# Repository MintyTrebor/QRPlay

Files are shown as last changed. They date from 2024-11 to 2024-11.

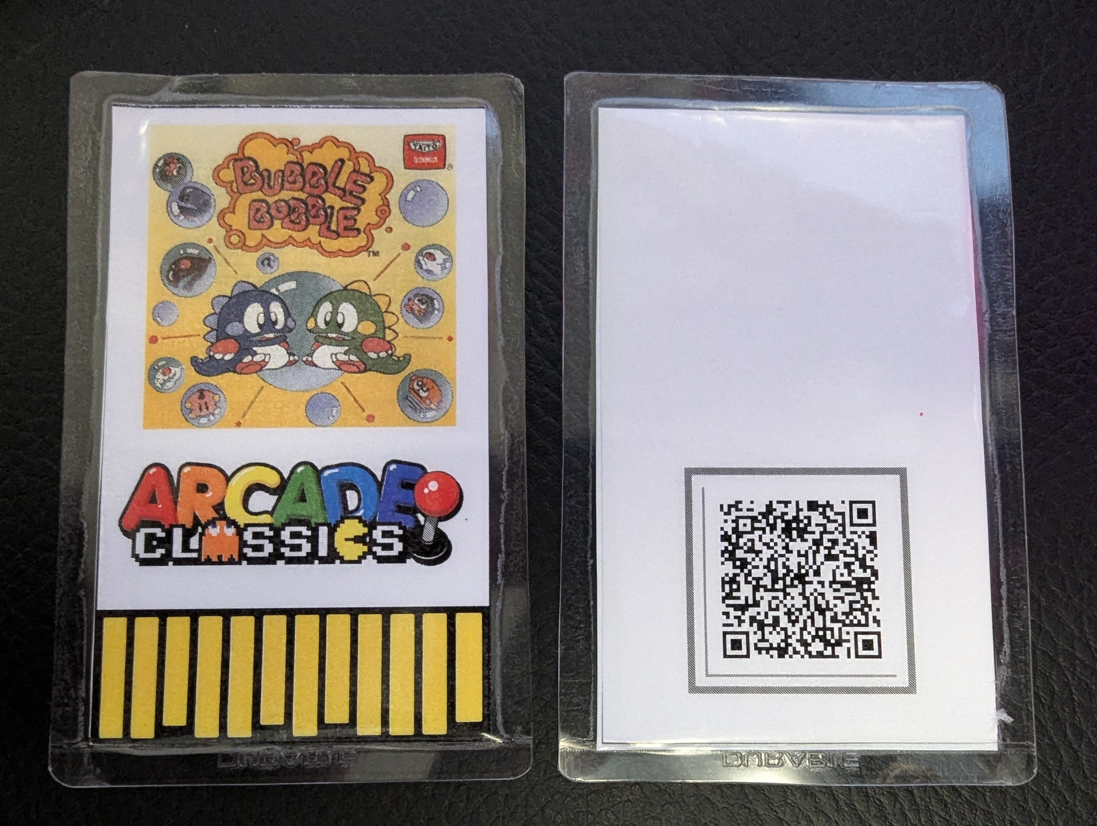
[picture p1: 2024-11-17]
media/PXL_20241114_154618407.jpg

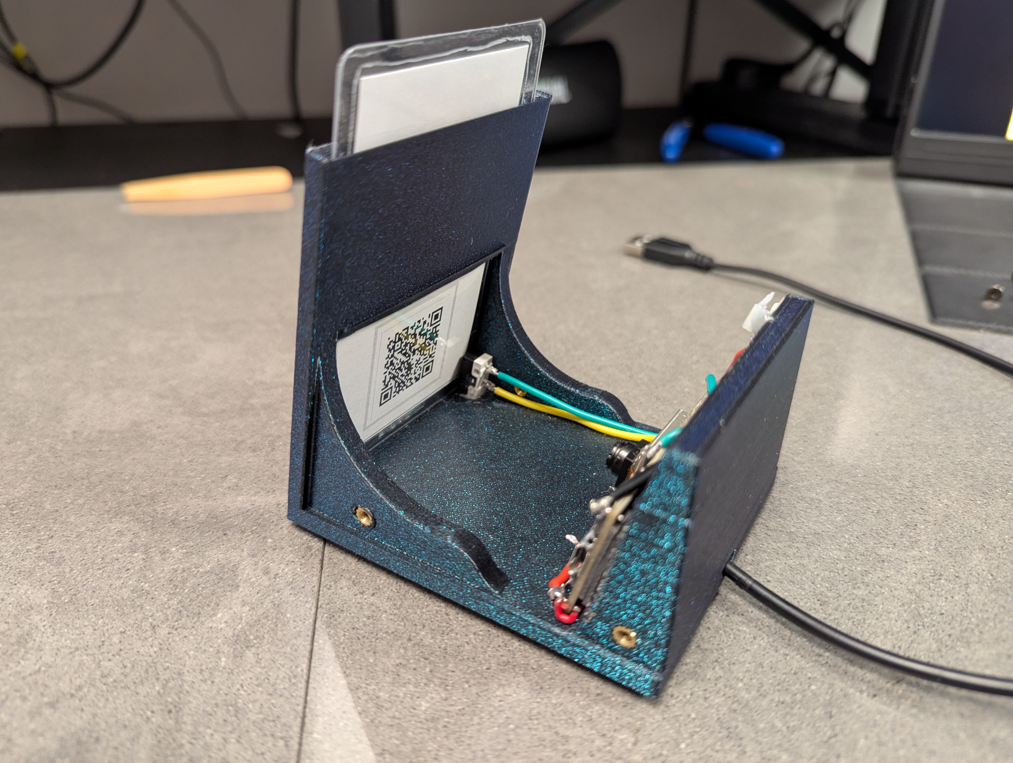
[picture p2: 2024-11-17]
media/PXL_20241117_150639216.jpg

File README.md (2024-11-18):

# QRPlay
ESP32-CAM QR Code MiSTer Game Launcher Project  

A DIY QR code reader using an ESP32-CAM module and a 3d printed case.  
Allows game launching on the MiSTer from a simple printed QR code over wifi.  

Uses the MiSTer Extensions Remote API - https://github.com/wizzomafizzo/mrext  - all credit goes to wizzoma for enabling this project with the Remote API.  

Project took about a day to complete and cost ~£25, which includes enough self laminating pouches for 100 QR Code Game Cards.  

Need soldering skills, and a working Arduino-IDE software.  

WIP Project - More instructions etc soon  

I did this just to see if it was possible, I think the NFC Zaparoo is a superior turn-key solution https://zaparoo.org/.

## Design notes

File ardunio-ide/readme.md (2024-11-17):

Arduino IDE Sketch  

To setup the Arduino-IDE for the Wroover ESP32-CAM board you will need the add the following board manager address in  
File - Preferences - Additional boards manager URLs  
https://raw.githubusercontent.com/espressif/arduino-esp32/gh-pages/package_esp32_index.json  
  
From Tools menu select Board - Boards Manager then select the "ESP32 Wrover Module"  

Needs the following Libraries Installed from the library Manager via Sketch - Include Library - Manage Libraries
- ezButton  

Also need to download the following github library as a zip and manually install via Sketch - Include Library - Add .zip library
https://github.com/MintyTrebor/ESP32QRCodeReader/tree/master

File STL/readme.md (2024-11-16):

STL Files for QR reader case - PLA - 0.2 Layer Height - I did not need Supports for base (bridging worked fine for me), supports may be needed for usb access hole in lid.  

CAD in onshape : https://cad.onshape.com/documents/70a1ef9716001ccbec5011c4/w/8f8471596bb90dc4432d828f/e/a0d7be243dedb3e33a138d39  
  
You will also need to print this Cameral Focus tool  
https://www.thingiverse.com/thing:4844956/files

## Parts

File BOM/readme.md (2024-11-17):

The following items are required to build the reader:
  
- 1x Wrover ESP32-CAM Module  - https://www.amazon.co.uk/dp/B09Z2GCCJZ  (https://randomnerdtutorials.com/getting-started-freenove-esp32-wrover-cam/)
  
- 1x White 5v LED - 2 wire LED from strip - I used an LED from this strip https://www.amazon.co.uk/dp/B09JP3JNXQ?ref=ppx_yo2ov_dt_b_fed_asin_title&th=1  

- Laminating Card Pouches for 54mmx90mm card size - https://www.amazon.co.uk/dp/B006O8A7EQ?ref=ppx_yo2ov_dt_b_fed_asin_title

- 1x Micro Switch - https://www.amazon.co.uk/gp/product/B015W8S8NA/ref=ppx_yo_dt_b_search_asin_title?ie=UTF8&psc=1

- 4 x M3 Heat inserts

- 4 x M3 6mm bolts

- 1 x 10k Resistor 

Optional  
  
- Sacrificial USB cable for power

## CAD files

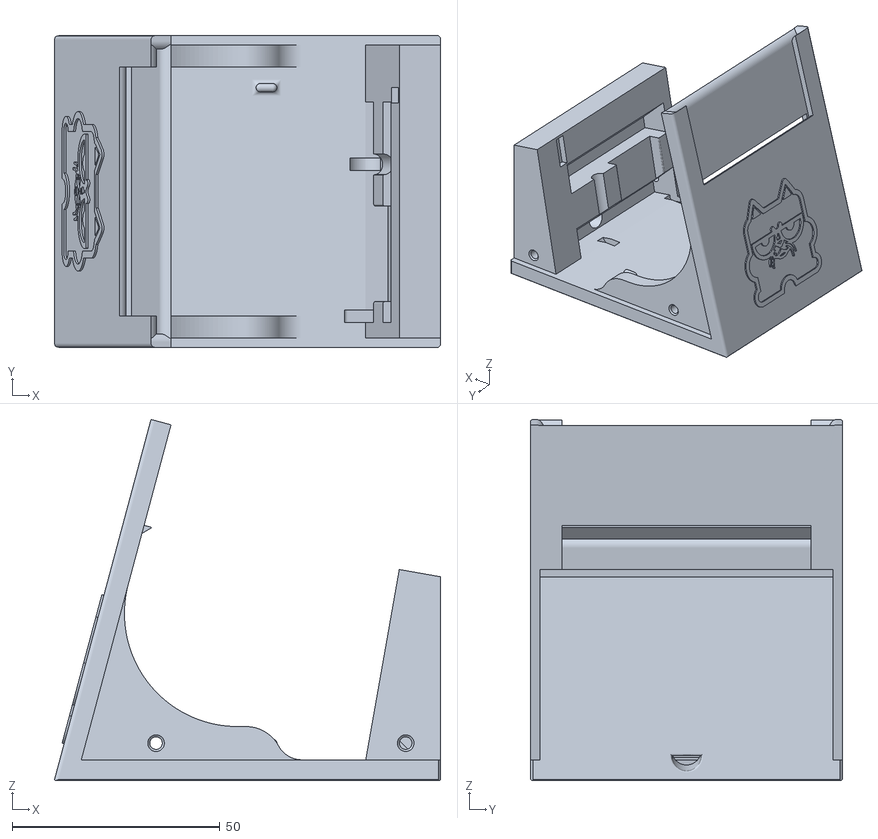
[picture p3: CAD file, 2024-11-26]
STL/QRPlay_Base.stl
92.9 x 75.0 x 86.9

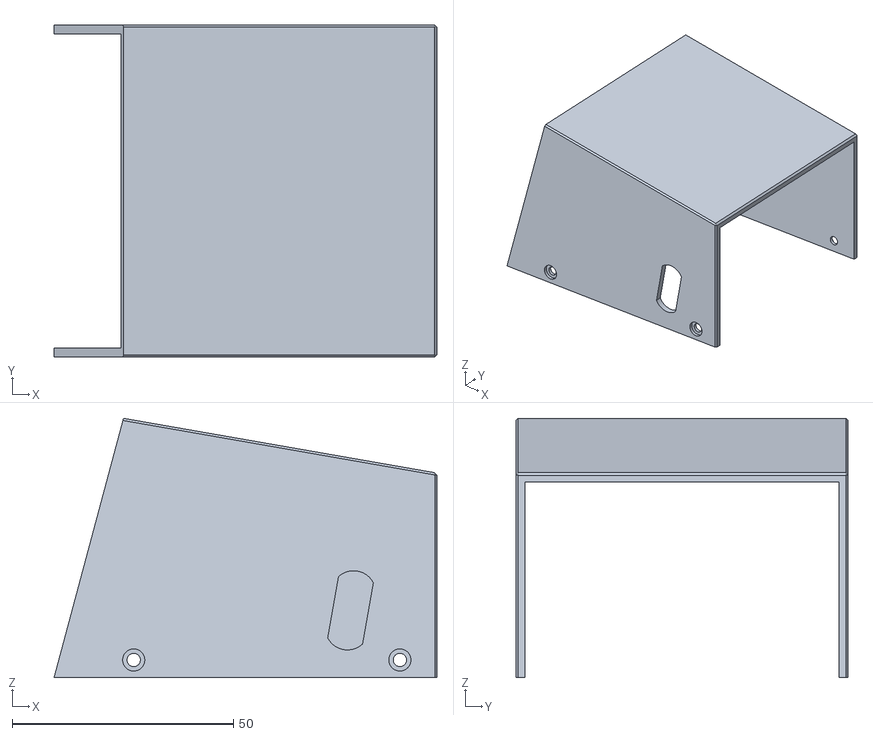
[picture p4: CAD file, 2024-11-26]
STL/QRPlay_Lid.stl
86.5 x 75.0 x 58.6

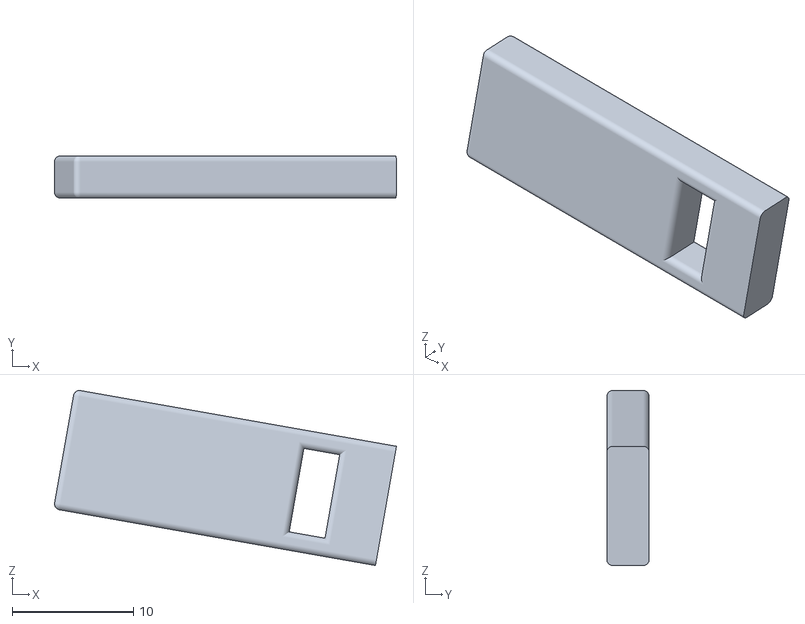
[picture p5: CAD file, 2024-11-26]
STL/QRPLay_LED_Mount.stl
28.2 x 3.50 x 14.5

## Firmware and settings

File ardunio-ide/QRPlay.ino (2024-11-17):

#include <Arduino.h>
#include <WiFi.h>
#include <HTTPClient.h>
#include <ESP32QRCodeReader.h>
#include <ezButton.h>

//Change these setting below
#define WIFI_SSID "#####"
#define WIFI_PASSWORD "*******"
//if mister.local does not work replace with IP of your MiSTer eg : http://192.168.1.23:8182/api/games/launch
#define WEBHOOK_URL "http://mister.local:8182/api/games/launch"
#define RESET_URL "http://mister.local:8182/api/launch/menu"
//change to false if you do not want the MiSTer to reset to the menu on removal of game card
#define RESET_ON_REMOVE true

//Set the GPIO Pin of the micro switch
#define BUTTON_PIN 32

//Change this if you use a different ESP32 Cam Model.
//The QR code Library currently supports:
//CAMERA_MODEL_ESP_EYE
//CAMERA_MODEL_WROVER_KIT
//CAMERA_MODEL_M5STACK_PSRAM
//CAMERA_MODEL_M5STACK_V2_PSRAM
//CAMERA_MODEL_M5STACK_WIDE
//CAMERA_MODEL_M5STACK_ESP32CAM
//CAMERA_MODEL_AI_THINKER
//CAMERA_MODEL_TTGO_T_JOURNAL
ESP32QRCodeReader reader(CAMERA_MODEL_WROVER_KIT);


struct QRCodeData qrCodeData;
struct QRCodeData EmptyQRCodeData;
bool isConnected = false;
ezButton limitSwitch(BUTTON_PIN);


bool connectWifi()
{
  if (WiFi.status() == WL_CONNECTED)
  {
    return true;
  }

  WiFi.begin(WIFI_SSID, WIFI_PASSWORD);
  int maxRetries = 10;
  while (WiFi.status() != WL_CONNECTED)
  {
    delay(500);
    Serial.print(".");
    maxRetries--;
    if (maxRetries <= 0)
    {
      return false;
    }
  }
  Serial.println("");
  Serial.println("WiFi connected");
  return true;
}

void callWebhook(String code)
{
  HTTPClient http;
  WiFiClient client;
  http.begin(client, WEBHOOK_URL);                   
  //Specify content-type header
  http.addHeader("Content-Type", "application/json");
  //post the QR data (should json {"path": "xxx"} str)
  int httpResponseCode = http.POST(code);
  Serial.print("HTTP Response code: ");
  Serial.println(httpResponseCode);            
  http.end();
}

void callResetMister()
{
  HTTPClient http;
  WiFiClient client;
  http.begin(client, RESET_URL);                   
  int httpResponseCode = http.POST("{}");
  Serial.print("HTTP Response code: ");
  Serial.println(httpResponseCode);            
  http.end();
}

void readQRCode()
{
  qrCodeData = EmptyQRCodeData;
  reader.begin();
  Serial.println("Begin QR Code reader");
  //set camera to greyscale for better detection
  sensor_t * s = esp_camera_sensor_get();
  s->set_special_effect(s, 2);
  bool waitForQR = true;
  while (waitForQR)
  {
    if (reader.receiveQrCode(&qrCodeData, 100))
    {
      Serial.println("Found QRCode");
      if (qrCodeData.valid)
      {
        Serial.print("Payload: ");
        Serial.println((const char *)qrCodeData.payload);
        callWebhook(String((const char *)qrCodeData.payload));
        waitForQR = false;
      }
      else
      {
        Serial.print("Invalid: ");
        Serial.println((const char *)qrCodeData.payload);
      }
    }
  }
  reader.end();
  Serial.println("End QR Code reader");

}

void setup()
{
  Serial.begin(115200);
  Serial.println();
  limitSwitch.setDebounceTime(50);
  reader.setup();
  Serial.println("Setup QRCode Reader");
  Serial.println("Waiting for Trigger");
}

void loop()
{ 
  bool connected = connectWifi();
  if (isConnected != connected)
  {
    isConnected = connected;
  }
  if (isConnected)
  {
    limitSwitch.loop(); 

    if(limitSwitch.isPressed()){
      Serial.println("Game Card Inserted");
      readQRCode();
    }

    if(limitSwitch.isReleased()){
      Serial.println("Game Card Removed");
      if (RESET_ON_REMOVE){
        Serial.println("Resetting Mister Now!");
        callResetMister();
      }
      ESP.restart();
    }

    int state = limitSwitch.getState();

  }
  delay(300);
}
